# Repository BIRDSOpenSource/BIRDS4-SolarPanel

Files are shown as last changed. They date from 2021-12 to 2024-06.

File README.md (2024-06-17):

<div align="center">
  <a href="https://lean-sat.org/opensource/">
  
  </a>
</div>

 

# BIRDS4-SolarPanel
 Documentation for the Solar Panel Boards used in the BIRDS4 Satellite

## About the BIRDS4 Program:

The Mission Statement of the Project is:

> “By successfully building and operating first satellite of nation, advance toward indigenous space program in each country”

The project is led by Kyushu Institute of Technology in Japan and involves students from Philippines, Paraguay, Nepal, Turkey and Japan.

Satellite Names: Tsuru (Japan), Guarani-1 (Paraguay) and Maya-2 (Phillipines)

Stakeholders:  Paraguayan Space Agency, Polytechnic Faculty of National University of Asuncion, and Kyushu Institute of Technology (Kyutech) for Japan.

Project duration: 2018-2022

CubeSat: 1U (10x10x10) cm3

Weight: 1.13kg

Launch Date: 21st February 2021 

BIRDS-4 has 1 main missions in total; APRS Store and forward mission

## Organisation structure

```bash

├── .gitattributes
├── LICENSE
├── README.md
└── Solar panel
    ├── +X
    │   ├── B4_FM_+X_SOLAR_PANEL_v2.brd
    │   └── B4_FM_+X_SOLAR_PANEL_v2.sch
    ├── +Y
    │   ├── B4_FM_+Y_SOLAR_PANEL.brd
    │   └── B4_FM_+Y_SOLAR_PANEL.sch
    ├── +Z
    │   ├── B4_FM_+Z_SOLAR_PANEL.brd
    │   └── B4_FM_+Z_SOLAR_PANEL.sch
    ├── -X
    │   ├── B4_FM_-X_SOLAR_PANEL_v2.brd
    │   └── B4_FM_-X_SOLAR_PANEL_v2.sch
    ├── -Z
    │   ├── B4_FM_-Z_SOLAR_PANEL.brd
    │   └── B4_FM_-Z_SOLAR_PANEL.sch
    └── B4_FM_solar_panel_List_20190923.xlsx
```

> [!CAUTION]
> The files `.sch` and `.brd` files in this repositiry were created using Eagle software.
 
For those that want to import these files into 
KiCAD7 [here's how you do it](https://community.element14.com/technologies/open-source-hardware/b/blog/posts/working-with-kicad-7-importing-eagle-files) 
 or KiCAD5.1 [here's how you do it](https://www.youtube.com/watch?v=RBc02MwpKxk&t=1s).
## Features

## I like this project, can I help you?
You are welcome 🙂

* Give us a star ⭐
* Watch repository to be notified about updates 👀
* If you will find some errors, report them in Issues 🐞
* Try Birds designs on some real computer and let us know how it worked in Discussions. 💬
* We would greatly appreciate if you would also tell others about this ecosystem, it helps us to improve BIRDS Open Source. Thank you!

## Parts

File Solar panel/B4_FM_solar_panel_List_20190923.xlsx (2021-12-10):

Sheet: B4_FM_+Z_panel_list_20190923
B4_FM_+Z_SOLAR_PANEL_2019.09.23 |  |  |  |  |  | single satellite | for 3 satellites | support +Z | Soldering tot. | Extra send | Total send P-ban
Part | Value | Package | Library | Position (mm) | Orientation | 1 | 3 | 3
C1 | 1uF | C2012 | adafruit | (15.3 78.38) | MR0 | 1 | 3 | 3 | 6 | 3 | 9
C2 |  | C2012 | adafruit | (37.56 77.36) | MR270 | 1 | 3 | 3 | 6 | 3 | 9
D1 |  | SOD-123FL | adafruit | (36.28 40.92) | R0 | 1 | 3 | 3 | 6 | 3 | 9
D2 |  | SOD-123FL | adafruit | (76.8 56.24) | R270 | 1 | 3 | 3 | 6 | 3 | 9
R1 |  | R0402 | adafruit | (30.03 78.31) | MR180 | 1 | 3 | 3 | 6 | 3 | 9
U$1 | HEADER12PIN | HEADER12PIN | BIRDS | (17.51 83.275) | MR90 | 1 | 3 | 3 | 6 | 3 | 9
U$3 | LMT84DCKT | SOT65P210X110-5N | LMT84DCKT | (23.39 79.06) | MR0 | 1 | 3 | 3 | 6 | 3 | 9

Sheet: B4_FM_+Y_Panel_list_20190923
B4_FM_+Y_SOLAR_PANEL_2019.09.23 |  |  |  |  |  | single satellite | 1 satellite | for 3 satellites | support +Z | Soldering tot. | Extra part send | Total send P-ban
Part | Value | Package | Library | Position (mm) | Orientation | 1 | 2 | 3 | 3
C1 | 1uF | C0805 | adafruit | (31.425 81.72) | R180 | 1 | 2 | 6 | 3 | 6 | 3 | 9
C2 | 1uF | C0805 | adafruit | (40.6 81.5) | R270 | 1 | 2 | 6 | 3 | 6 | 3 | 9
D1 |  | SOD-123FL | adafruit | (45.1 64) | MR90 | 1 | 2 | 6 | 3 | 6 | 3 | 9
D2 |  | SOD-123FL | adafruit | (78.1 39.8) | MR180 | 1 | 2 | 6 | 3 | 6 | 3 | 9
R1 |  | R0402 | adafruit | (36.5 81.9) | R90 | 1 | 2 | 6 | 3 | 6 | 3 | 9
U$1 | HEADER12PIN | HEADER12PIN | BIRDS | (30.3 91.475) | R270 | 1 | 2 | 6 | 3 | 6 | 3 | 9
U$3 | LMT84DCKT | SOT65P210X110-5N | LMT84DCKT | (33.55 77.95) | R180 | 1 | 2 | 6 | 3 | 6 | 3 | 9

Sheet: B4_FM_+X_panel_List_20190923
B4_FM_+X_SOLAR_PANEL_2019.09.23 |  |  |  |  |  | single satellite | 1 satellite | for 3 satellites | support +Z | Soldering tot. | Extra part send | Total send P-ban
Part | Value | Package | Library | Position (mm) | Orientation | 1 | 2 | 3 | 3
C1 | 0.1uF | C0805 | adafruit | (24.1244 13.7562) | MR270 | 1 | 2 | 6 | 3 | 6 | 3 | 9
C2 |  | C0805 | adafruit | (25.1824 19.1022) | MR0 | 1 | 2 | 6 | 3 | 6 | 3 | 9
D1 |  | SOD-123FL | adafruit | (34.655 48.708) | R270 | 1 | 2 | 6 | 3 | 6 | 3 | 9
R1 |  | R0402 | adafruit | (25.0454 17.0572) | MR180 | 1 | 2 | 6 | 3 | 6 | 3 | 9
SDA1 | S1751-46R | S1751-46R | BIRDS3_MSN_BRD_II | (4.37 18.09) | MR0 | 1 | 2 | 6 | 3 | 6 | 3 | 9
SDA3 | S1751-46R | S1751-46R | BIRDS3_MSN_BRD_II | (4.34 13.65) | MR0 | 1 | 2 | 6 | 3 | 6 | 3 | 9
U$1 | HEADER12PIN | HEADER12PIN | BIRDS | (30.1 9.3) | MR90 | 1 | 2 | 6 | 3 | 6 | 3 | 9
U$3 | LMT84DCKT | SOT65P210X110-5N | LMT84DCKT | (20.0894 15.0232) | MR270 | 1 | 2 | 6 | 3 | 6 | 3 | 9

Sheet: B4_FM_-Z_Panel_List_20190923
B4_FM_+X_SOLAR_PANEL_2019.09.23 |  |  |  |  |  | single satellite | 1 satellite | for 3 satellites | support +Z | Soldering tot. | Extra part send | Total send P-ban
Part | Value | Package | Library | Position (mm) | Orientation | 1 | 2 | 3 | 3
C1 | 1uF | C0805 | adafruit | (9.63 29.965) | MR0 | 1 | 2 | 6 | 3 | 6 | 3 | 9
C2 | 1uF | C0805 | adafruit | (9.4295625 39.828596875) | MR0 | 1 | 2 | 6 | 3 | 6 | 3 | 9
D1 |  | SOD-123FL | adafruit | (10.4454 45.214) | R270 | 1 | 2 | 6 | 3 | 6 | 3 | 9
R1 | 1kohm | R0402 | adafruit | (9.5804375 37.630234375) | MR180 | 1 | 2 | 6 | 3 | 6 | 3 | 9
SDA1 | S1751-46R | S1751-46R | BIRDS3_MSN_BRD_II | (16.9164 80.2386) | MR270 | 1 | 2 | 6 | 3 | 6 | 3 | 9
SDA2 | S1751-46R | S1751-46R | BIRDS3_MSN_BRD_II | (20.2438 80.264) | MR90 | 1 | 2 | 6 | 3 | 6 | 3 | 9
U$1 | HEADER12PIN | HEADER12PIN | BIRDS | (9.125 78.2) | MR180 | 1 | 2 | 6 | 3 | 6 | 3 | 9
U$3 | LMT84DCKT | SOT65P210X110-5N | LMT84DCKT | (9.68 34.21) | MR270 | 1 | 2 | 6 | 3 | 6 | 3 | 9

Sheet: B4_FM_-X_Panel_List_20190923
B4_FM_+X_SOLAR_PANEL_2019.09.23 |  |  |  |  |  | single satellite | 1 satellite | for 3 satellites | support +Z | Soldering tot. | Extra part send | Total send P-ban
Part | Value | Package | Library | Position (mm) | Orientation | 1 | 2 | 3 | 3
C1 | 1uF | C0805 | adafruit | (26.784378125 14.70585 | 9375) MR270 | 1 | 2 | 6 | 3 | 6 | 3 | 9
C2 | 1uF | C0805 | adafruit | (19.0838 14.9234) | MR270 | 1 | 2 | 6 | 3 | 6 | 3 | 9
D1 |  | SOD-123FL | adafruit | (80.32 49.82) | R270 | 1 | 2 | 6 | 3 | 6 | 3 | 9
R1 | 1kohm | R0402 | adafruit | (21.8062 17.0744) | MR0 | 1 | 2 | 6 | 3 | 6 | 3 | 9
SDA1 | S1751-46R | S1751-46R | BIRDS3_MSN_BRD_II | (10.0838 19.8374) | MR90 | 1 | 2 | 6 | 3 | 6 | 3 | 9
SDA3 | S1751-46R | S1751-46R | BIRDS3_MSN_BRD_II | (5.9436 19.812) | MR270 | 1 | 2 | 6 | 3 | 6 | 3 | 9
SOLARCELL_A |  | SC_A | SC_A | (1.4 57) | R0 | 1 | 2 | 6 | 3 | 6 | 3 | 9
SOLARCELL_B | SC_B | SC_B | SC_B-2 | (1.7 11) | R0 | 1 | 2 | 6 | 3 | 6 | 3 | 9
U$1 | HEADER12PIN | HEADER12PIN | BIRDS | (30.1 9.3) | MR90 | 1 | 2 | 6 | 3 | 6 | 3 | 9
U$3 | LMT84DCKT | SOT65P210X110-5N | LMT84DCKT | (23.3408 14.599) | MR180 | 1 | 2 | 6 | 3 | 6 | 3 | 9

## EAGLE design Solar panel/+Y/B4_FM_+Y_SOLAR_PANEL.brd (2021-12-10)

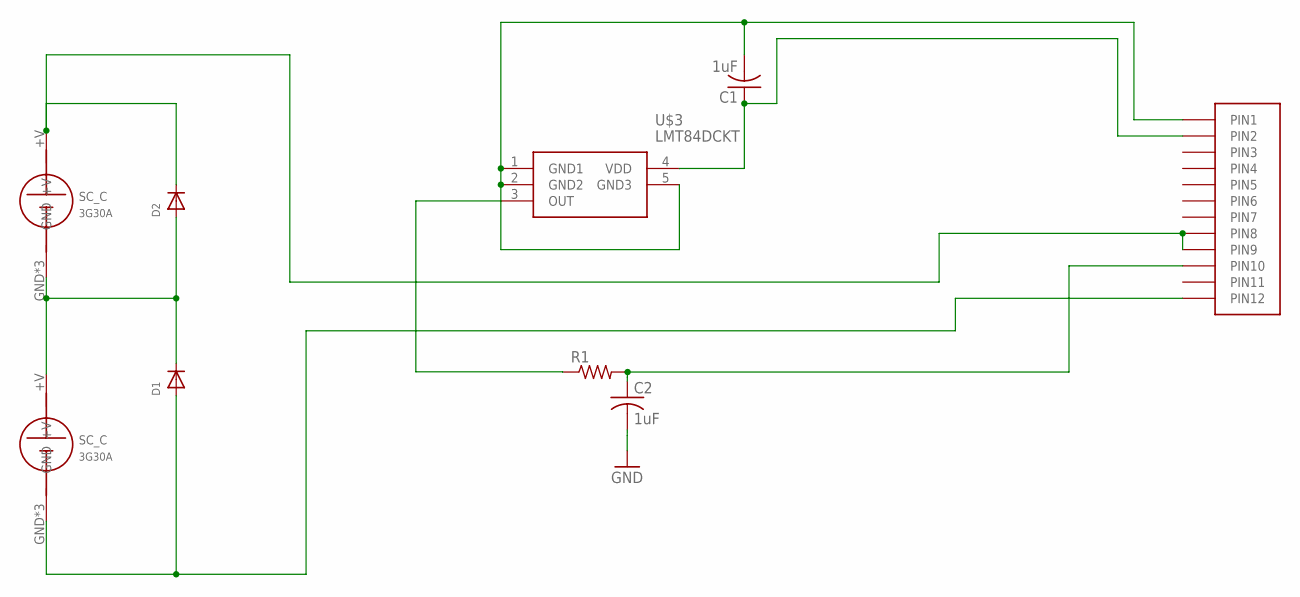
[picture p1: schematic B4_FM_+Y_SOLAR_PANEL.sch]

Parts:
C1, C2: 1uF; C0805
D1, D2: DIODE_SOD-123FL; SOD-123FL
R1: R-US_R0402; R0402
U$1: HEADER12PIN
U$3: LMT84DCKT; SOT65P210X110-5N
U$4, U$5: SC_C

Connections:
+V: D2.C, U$1.P8 (PIN8), U$1.P9 (PIN9), U$4.+V
GND: C1.2, C2.2, D1.A, U$1.P1 (PIN1), U$1.P12 (PIN12), U$3.1 (GND1), U$3.2 (GND2), U$3.5 (GND3), U$5.GND, U$5.GND1 (GND), U$5.GND2 (GND)
unnamed: D1.C, D2.A, U$4.GND, U$4.GND1 (GND), U$4.GND2 (GND), U$5.+V
unnamed: R1.1, U$3.3 (OUT)
unnamed: C2.1, R1.2, U$1.P10 (PIN10)
unnamed: C1.1, U$1.P2 (PIN2), U$3.4 (VDD)

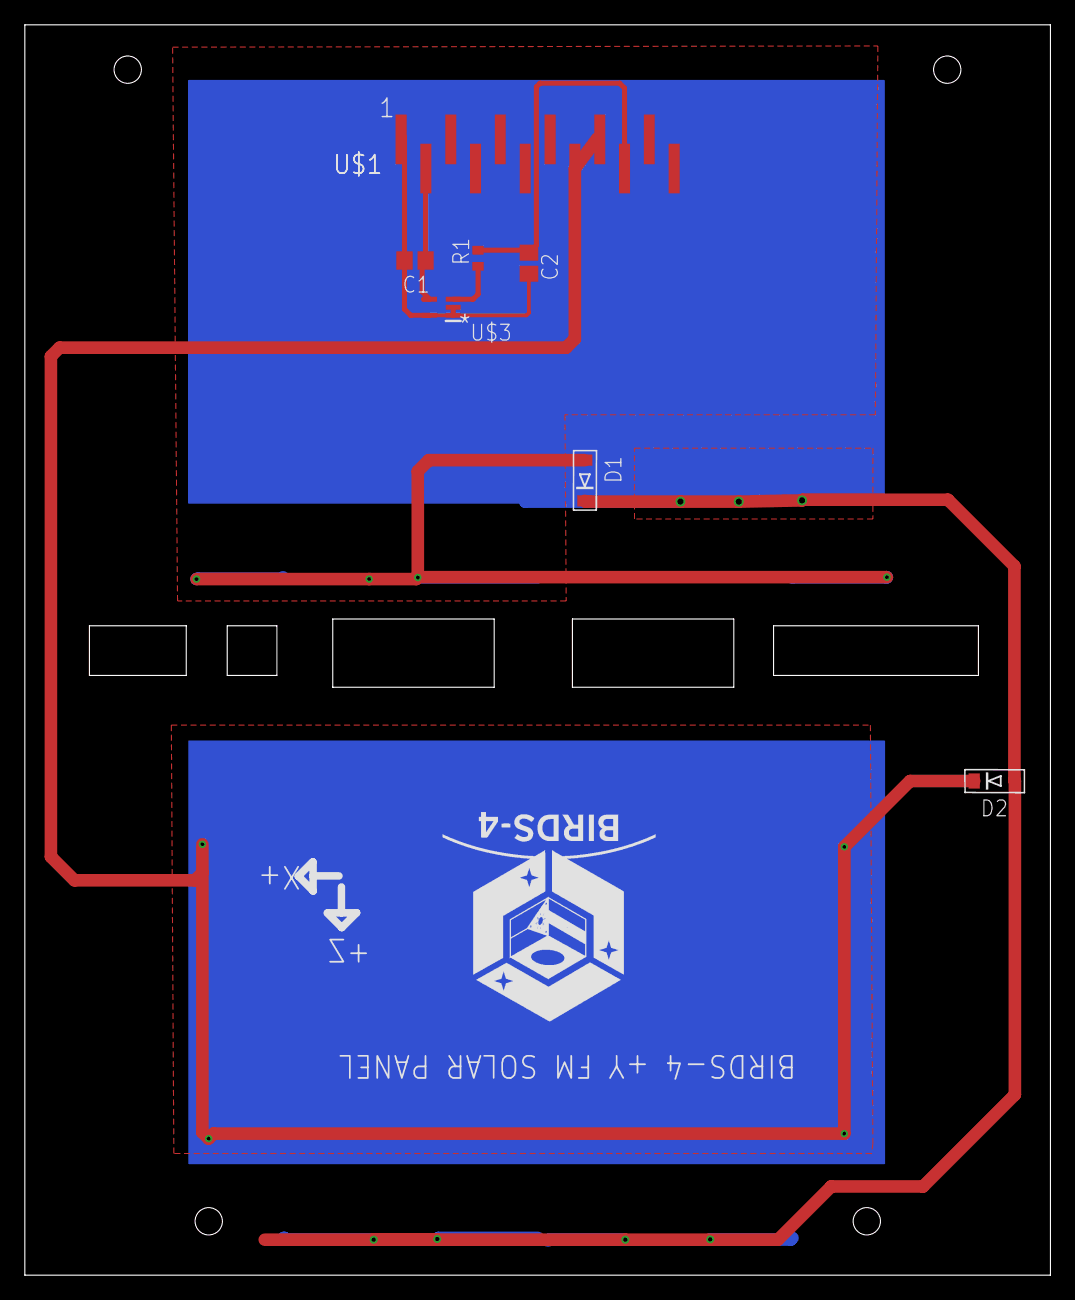
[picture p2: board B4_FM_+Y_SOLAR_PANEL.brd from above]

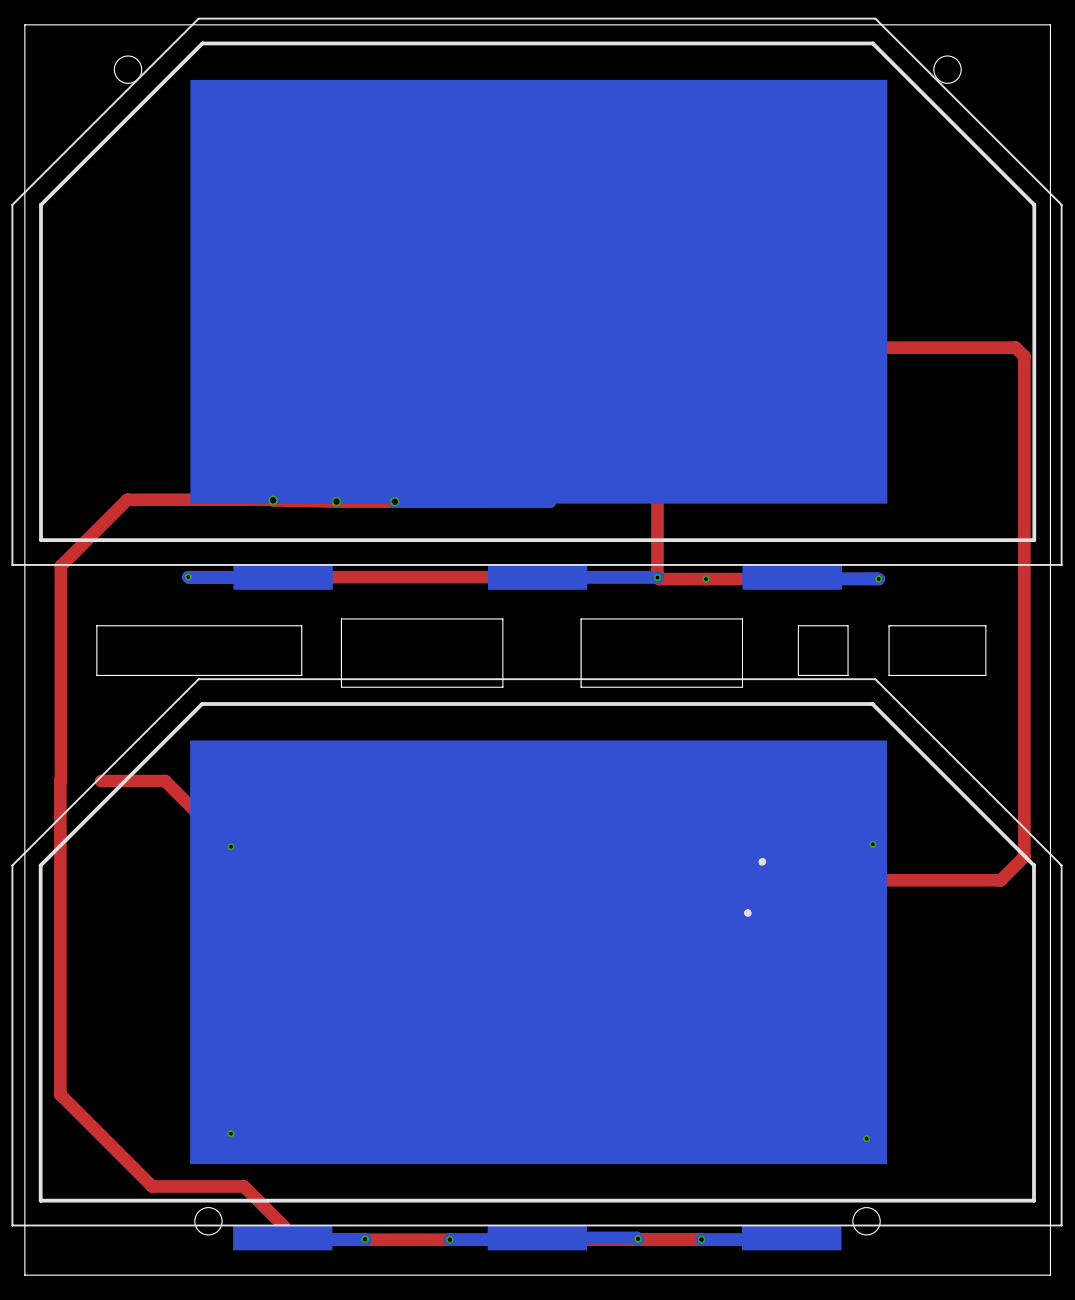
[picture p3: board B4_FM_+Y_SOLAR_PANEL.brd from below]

Board: 2 copper layers, 82.6 x 100.7 mm, 9 parts (2 on the bottom side), 6 nets.
